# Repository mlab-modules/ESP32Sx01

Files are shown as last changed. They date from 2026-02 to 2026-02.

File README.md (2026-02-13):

# ESP32Sx01 - ESP32-S3 MLAB module

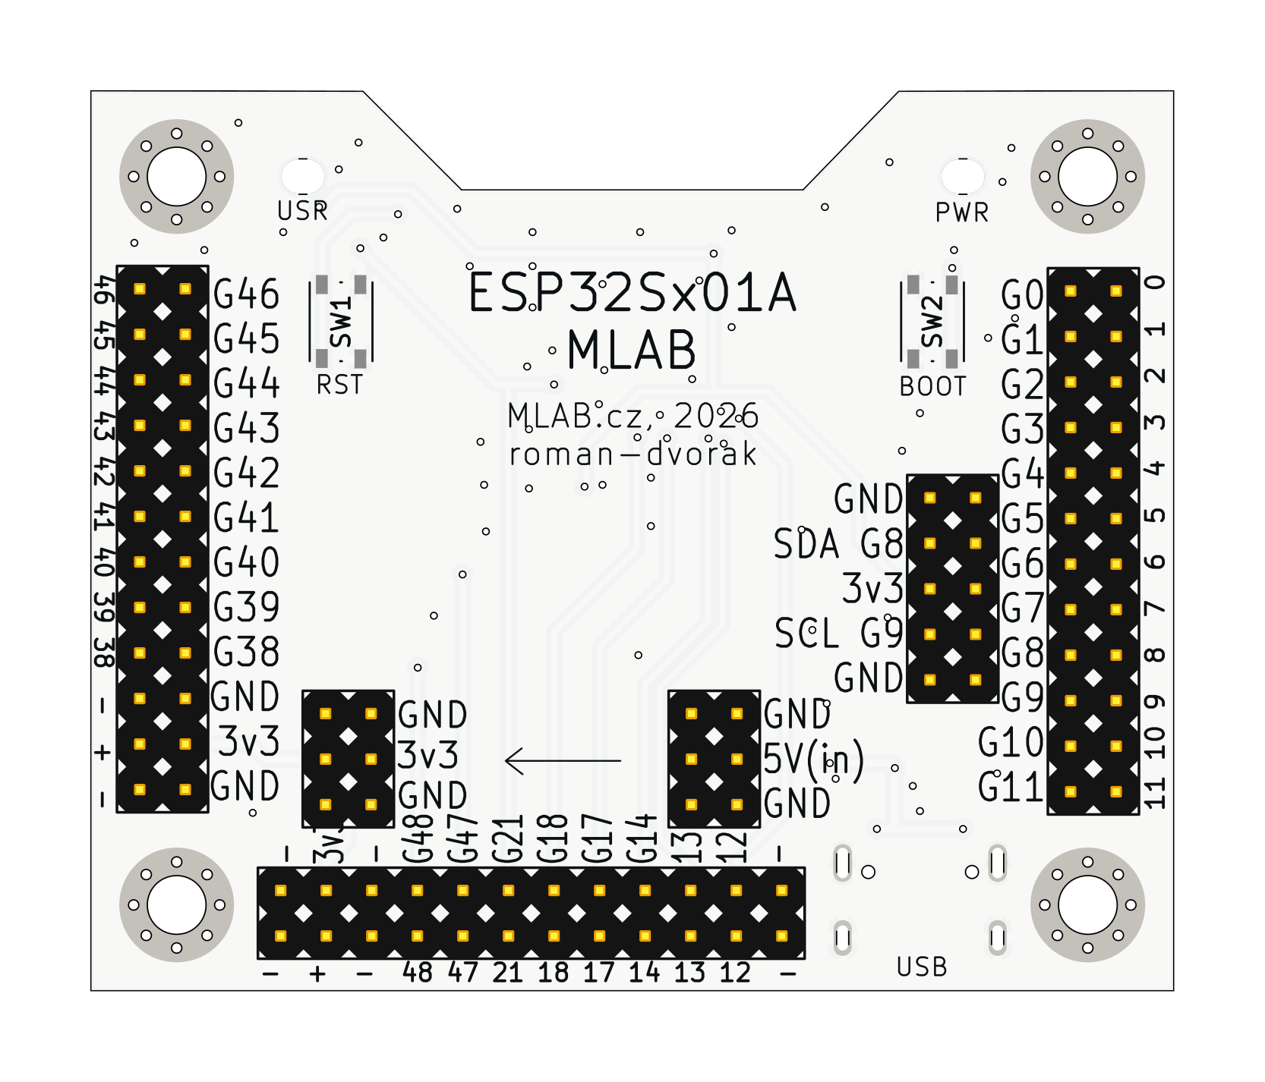
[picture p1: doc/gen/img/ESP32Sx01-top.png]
Module Photo


## Description

ESP32Sx01 is a compact MLAB development module based on the ESP32-S3-MINI-1 microcontroller module from Espressif. The module provides a complete development platform for IoT applications with WiFi and Bluetooth connectivity.

## Key Features

* **Microcontroller**: ESP32-S3-MINI-1
  * Dual-core Xtensa® 32-bit LX7 microprocessor
  * WiFi 802.11 b/g/n (2.4 GHz)
  * Bluetooth® 5 (LE)
  * Up to 8 MB Flash
  * Optional 2 MB PSRAM
* **USB Connectivity**: 2x USB Type-C connectors
  * USB programming and debugging
  * ESD protection (USBLC6-2SC6)
* **Power Supply**:
  * Onboard 3.3V regulator (NCP1117-3.3)
  * Input voltage: +5V via USB or external connector
  * Output: +3.3V for ESP32-S3 and peripherals
* **User Interface**:
  * Reset button
  * Power LED (Green)
  * User LED (Red)
* **Expansion**: 
  * MLAB standard connectors
  * Multiple pin headers for GPIO access
  * Crystal oscillator for precise timing
* **Protection**:
  * USB ESD protection

## Applications

* IoT sensor nodes
* WiFi/Bluetooth gateways
* Home automation controllers
* Wireless data logging
* Educational projects
* Rapid prototyping

## Pinout
The module provides access to ESP32-S3 GPIO pins through standard MLAB connectors and pin headers. Refer to the schematic for detailed pinout information.

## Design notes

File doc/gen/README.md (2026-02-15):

# PCB

Board size: 60.45x50.29 mm (2.38x1.98 inches)

- This is the size of the rectangle that contains the board
- Thickness: 1.6 mm (63 mils)
- Material: FR4
- Finish: None
- Layers: 2
- Copper thickness: 35 µm

Solder mask: TOP / BOTTOM

- Color: Green

Silk screen: TOP / BOTTOM

- Color: White

Stackup:

| Name | Type | Color | Thickness [µm]| Material | Er | Loss tan |
|---|---|---|---|---|---|---|
| F.SilkS | Top Silk Screen | | | | | |
| F.Paste | Top Solder Paste | | | | | |
| F.Mask | Top Solder Mask | | 10 | | | |
| F.Cu | copper | | 35 | | | |
| dielectric 1 | core | | 1510 | FR4 | 4.5 | 0.020 |
| B.Cu | copper | | 35 | | | |
| B.Mask | Bottom Solder Mask | | 10 | | | |
| B.Paste | Bottom Solder Paste  | | | | | |
| B.SilkS | Bottom Silk Screen | | | | | |

# Important sizes

Clearance: 0.2 mm (8 mils)

Track width: 0.2 mm (8 mils)

- By design rules: 0.0 mm (0 mils)

Drill: 0.4 mm (16 mils)

- Vias: 0.4 mm (16 mils) [Design: 0.4 mm (16 mils)]
- Pads: 0.6 mm (24 mils)
- The above values are real drill sizes, they add 0.1 mm (4 mils) to plated holes (PTH)

Via: 0.6/0.3 mm (24/12 mils)

- By design rules: 0.25/0.3 mm (10/12 mils)
- Micro via: yes [0.2/0.1 mm (8/4 mils)]
- Buried/blind via: yes
- Total: 70 (thru: 70 buried/blind: 0 micro: 0)

Outer Annular Ring: 0.1 mm (4 mils)

- By design rules: 0.1 mm (4 mils)

Eurocircuits class: 8C
- Using min drill 0.35 mm for an OAR of 0.1 mm

# General stats

Components count: (SMD/THT)

- Top: 2/6 (SMD + THT)
- Bottom: 24/1 (SMD + THT)

Defined tracks:

- 0.3 mm (12 mils)
- 0.4 mm (16 mils)

Used tracks:

- 0.2 mm (8 mils) (7) defined: no
- 0.25 mm (10 mils) (19) defined: no
- 0.3 mm (12 mils) (119) defined: yes
- 0.4 mm (16 mils) (143) defined: yes

Defined vias:

Used vias:

- 0.6/0.3 mm (24/12 mils) (Count: 70, Aspect: 2.7 A) defined: no

Holes (excluding vias):

- 0.5 mm (20 mils) (32)
- 0.65 mm (26 mils) (2)
- 0.89 mm (35 mils) (94)
- 3.2 mm (126 mils) (4)

Oval holes:

- 0.6x1.4 mm (24x55 mils) (2)
- 0.6x1.7 mm (24x67 mils) (2)
- 1.9x2.4 mm (75x94 mils) (2)

Drill tools (including vias and computing adjusts and rounding):

- 0.4 mm (16 mils) (70)
- 0.6 mm (24 mils) (32)
- 0.65 mm (26 mils) (2)
- 0.7 mm (28 mils) (4)
- 1.0 mm (39 mils) (94)
- 1.9 mm (75 mils) (2)
- 3.3 mm (130 mils) (4)

Solder paste stats:

Using a paste with 87.75 % alloy, that has an specific gravity for the alloy of 7.4 g/cm³
and 1.0 g/cm³ for the flux. This paste has an specific gravity of  4.15 g/cm³.

The stencil thickness is  0.12 mm.

| Side | Pads with paste | Area [mm²] | Paste [g] |
|---|---|---|---|
| Top | 8 | 5.46 | 0.03 |
| Bottom | 138 | 119.78 | 0.60 |
| Total  | 146 | 125.24 | 0.62 |

Note: this is just an approximation to the theoretical value. Margins of the solder mask and waste aren't computed.

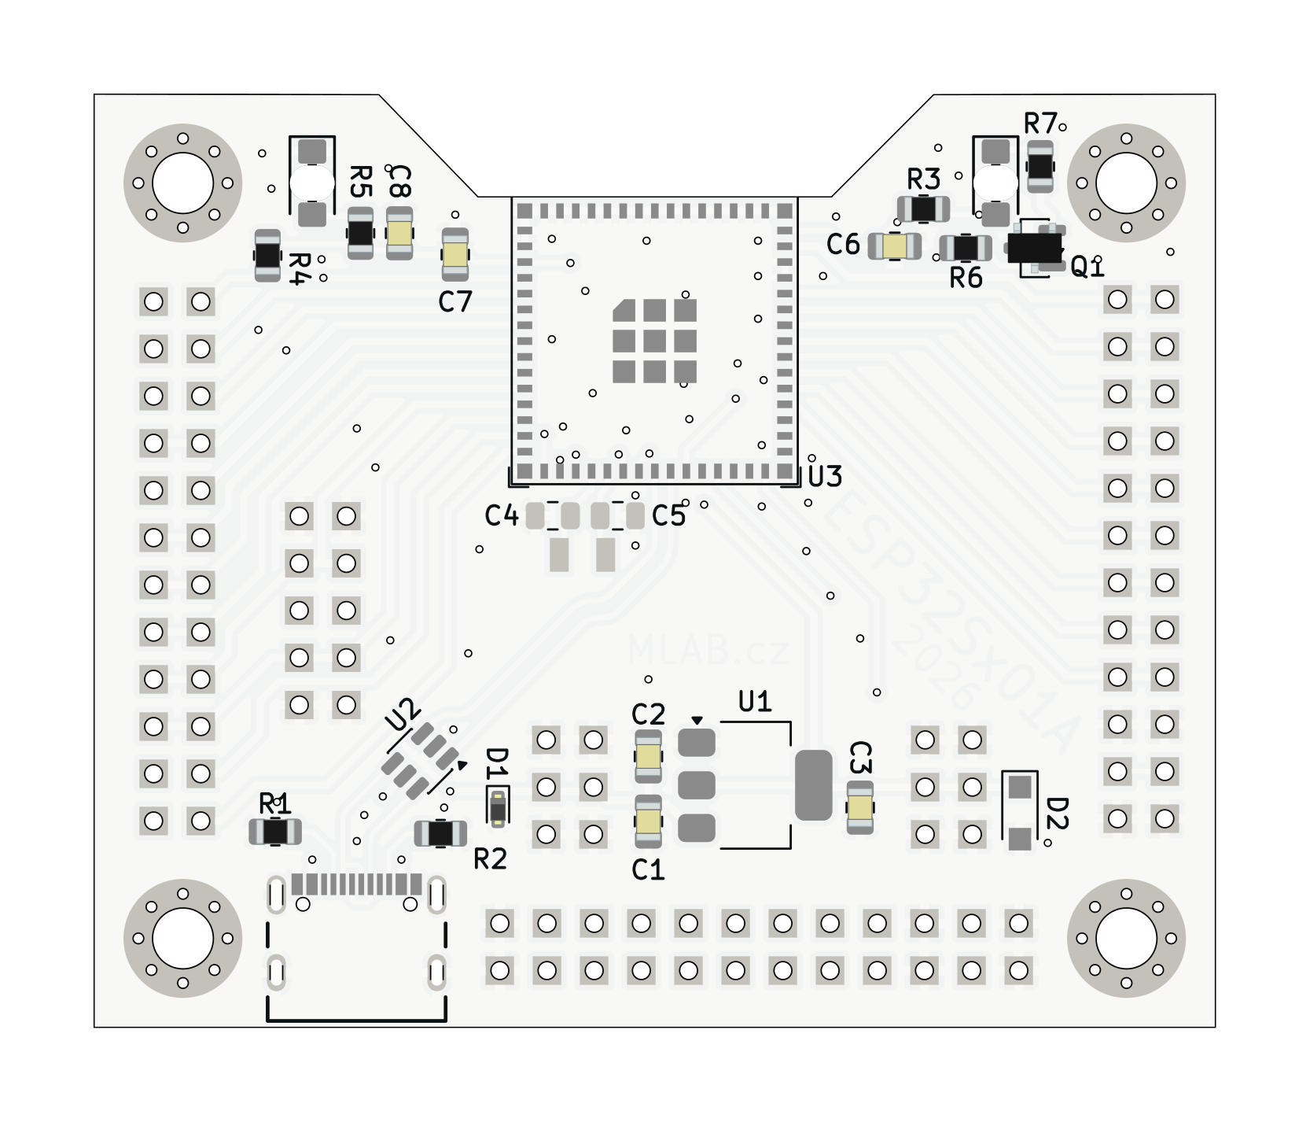
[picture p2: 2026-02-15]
doc/gen/img/ESP32Sx01-bottom.png

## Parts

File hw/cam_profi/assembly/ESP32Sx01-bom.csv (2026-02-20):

Component | Description | Part | References | Value | Footprint | Quantity Per PCB | Datasheet | obchod | ust_id
1 | Unpolarized capacitor, small symbol | C_Small | C1C6C7 | 100n | C_0805_2012Metric | 3 | ~ | TME | 5c70984712875079b91f8b4c
2 | Unpolarized capacitor, small symbol | C_Small | C2C3C8 | 10u | C_0805_2012Metric | 3 | ~ | TME | 5c70984712875079b91f8b53
3 | Zener diode, small symbol | D_Zener_Small | D2 | BZT52H-C3V6,115 | Nexperia_CFP3_SOD-123W | 1 | ~ |  | 650b35ab462c6d9e720543d0
4 | Zener diode, small symbol | D_Zener_Small | D1 | BZX585-B5V6.115 | D_SOD-523 | 1 | ~ |  | 60879d38128750769ee58e48
5 | Light emitting diode, small symbol | LED_Small | D4 | Green | LED_1206_KPTR | 1 | ~ | OK
6 | Light emitting diode, small symbol | LED_Small | D3 | Red | LED_1206_KPTR | 1 | ~ | OK
7 | 2x03 2.54 mm pitch header, 2 pins next to each other are connected | HEADER_2x03_PARALLEL | J1J6 | HEADER_1x03 | Straight_2x03 | 2
8 | 2x12 2.54 mm pitch header, 2 pins next to each other are connected | HEADER_2x12_PARALLEL | J3J4J5 | HEADER_1x12 | Straight_2x12 | 3
9 | 2x05 2.54 mm pitch header, 2 pins next to each other are connected | HEADER_2x05_PARALLEL | J7 | HEADER_2x05 | Straight_2x05 | 1
10 | USB 2.0-only Type-C Receptacle connector | USBC_USB4105-GF-A | J2 | USBC_USB4105-GF-A | USBC GCT_USB4105-GF-A | 1 | https://www.usb.org/sites/default/files/documents/usb_type-c.zip | OK | 5fa0f94612875025b397795e
11 | NPN transistor, base/collector/emitter | Q_NPN_BCE | Q1 | BC817-25 | SOT-23 | 1 | ~ | TME | 5c70984712875079b91f8aea
12 | Resistor, small symbol | R_Small | R5R6 | 200R | R_0805_2012Metric | 2 | ~ | TME | 5c70984512875079b91f897d
13 | Resistor, small symbol | R_Small | R7 | 390R | R_0805_2012Metric | 1 | ~ |  | 5fa12b6012875025b3977a16
14 | Resistor, small symbol | R_Small | R3R4 | 1k | R_0805_2012Metric | 2 | ~ | TME | 5c70984512875079b91f898c
15 | Resistor, small symbol | R_Small | R1R2 | 5k1 | R_0805_2012Metric | 2 | ~ | TME | 5fa0fc3e12875025b3977997
16 | Push button switch, generic, two pins | SW_Push | SW1SW2 | 434133025816 | SW_Push_1P1T_NO_Vertical_Wuerth_434133025816 | 2 | ~ | TME | 6998c49ed42e6e3c4d330f22
17 | Smallsized module supporting 2.4 GHz WiFi (802.11 b/g/n) and Bluetooth ® 5 (LE) Built around ESP32S3 series of SoCs, Xtensa ® dualcore 32bit LX7 microprocessor Flash up to 8 MB, optional 2 MB PSRAM in chip package 39 GPIOs, rich set of peripherals Onboard PCB antenna or external antenna connector | ESP32-S3-MINI-1 | U3 | ESP32-S3-MINI-1 | ESP32-S3-MINI-1 | 1 | https://www.espressif.com/sites/default/files/documentation/esp32-s3-mini-1_mini-1u_datasheet_en.pdf
18 | 1A Low drop-out regulator, Fixed Output 3.3V, SOT-223 | NCP1117-3.3_SOT223 | U1 | NCP1117-3.3 | SOT-223-3_TabPin2 | 1 | http://www.onsemi.com/pub_link/Collateral/NCP1117-D.PDF | TME | 5c70984712875079b91f8af9
19 | Very low capacitance ESD protection diode, 2 data-line, SOT-23-6 | USBLC6-2SC6 | U2 | USBLC6-2SC6 | SOT-23-6 | 1 | https://www.st.com/resource/en/datasheet/usblc6-2.pdf | TME | 5e82e0691287502a334a778c

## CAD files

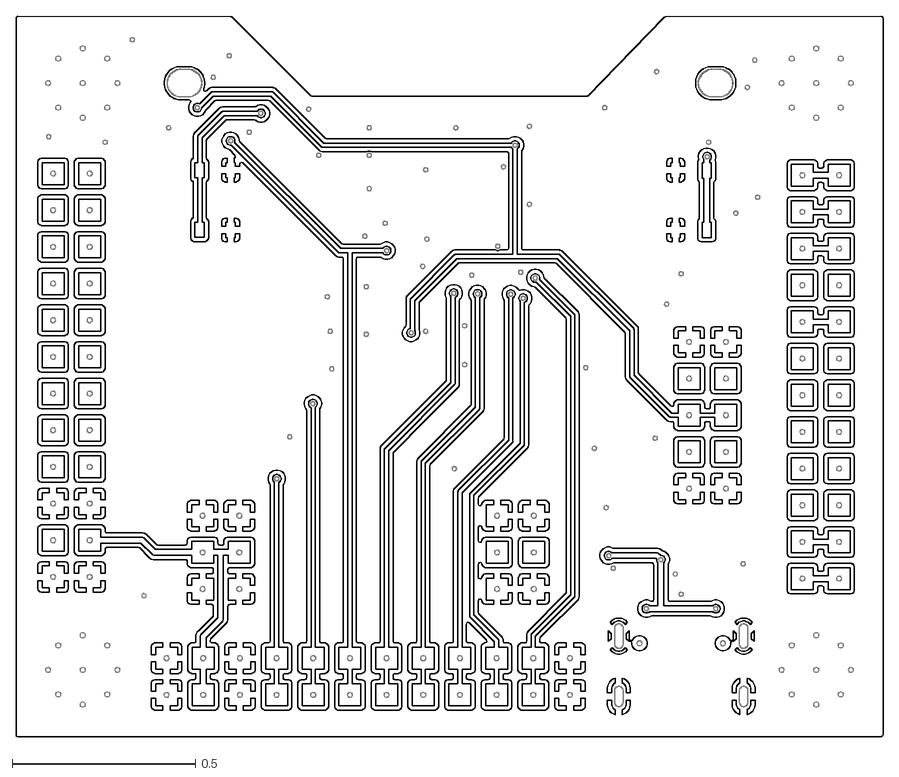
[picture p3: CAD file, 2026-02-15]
doc/gen/dxf/ESP32Sx01-F_Cu.dxf
2.36 x 1.96

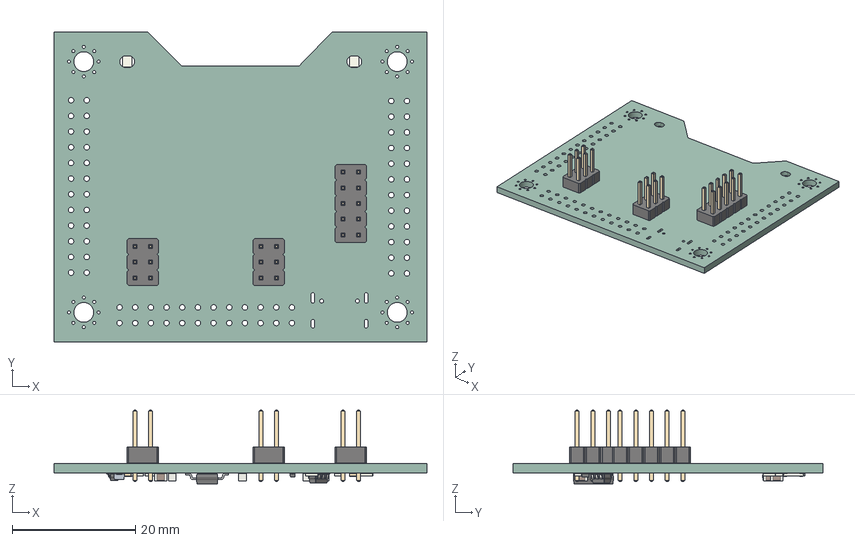
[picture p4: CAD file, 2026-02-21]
doc/gen/ESP32Sx01.step
60.5 x 50.3 x 11.9 mm
PinHeader_2x03_P2.54mm_Vertical x 2
PinHeader_2x05_P2.54mm_Vertical
R_0805_2012Metric x 7
C_0805_2012Metric x 6
LED_1206_3216Metric x 2
ESP32Sx01 1.10.1
SOT-223
D_SOD-523
SOT-23
SOT-23-6
kibot_rp9vfimv_PCB

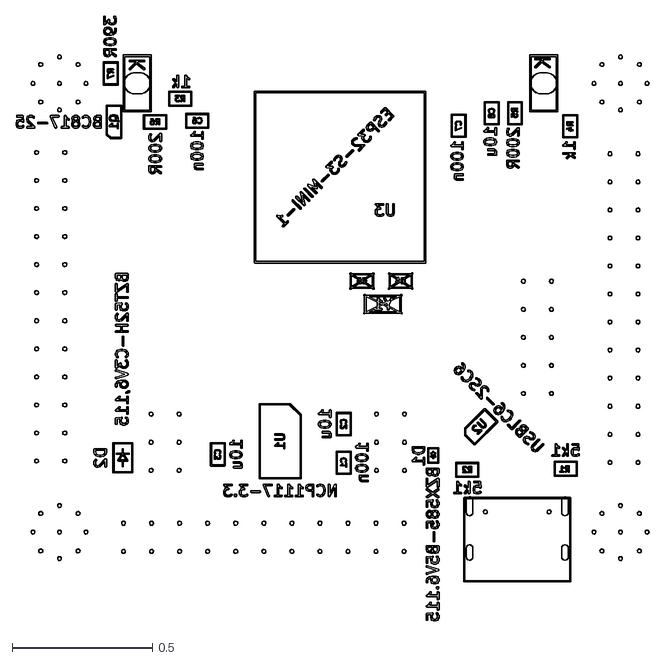
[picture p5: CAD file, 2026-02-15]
doc/gen/dxf/ESP32Sx01-B_Fab.dxf
2.26 x 2.16

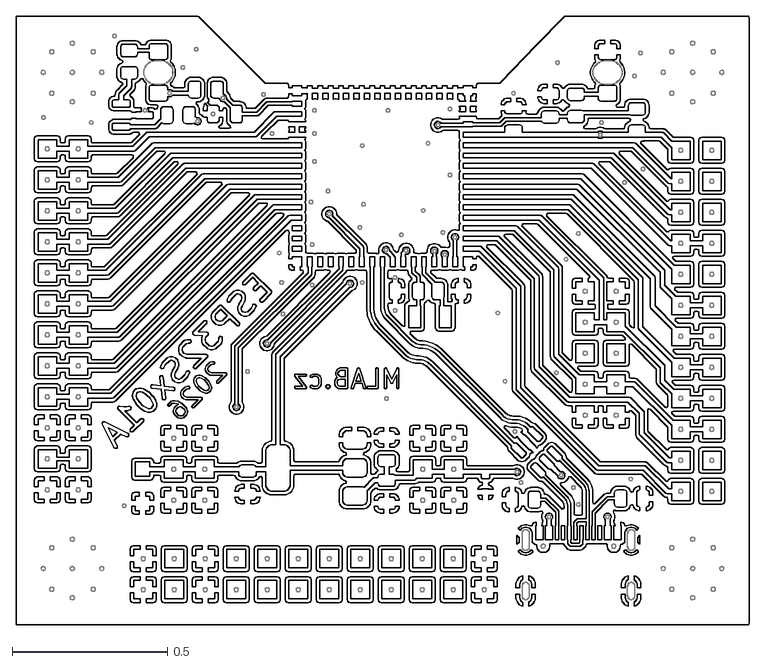
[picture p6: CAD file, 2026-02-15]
doc/gen/dxf/ESP32Sx01-B_Cu.dxf
2.36 x 1.96

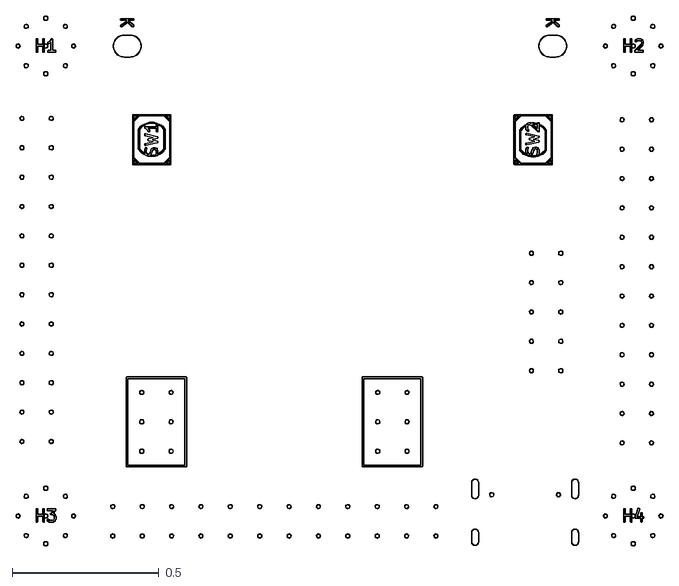
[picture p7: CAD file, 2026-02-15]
doc/gen/dxf/ESP32Sx01-F_Fab.dxf
2.20 x 1.80

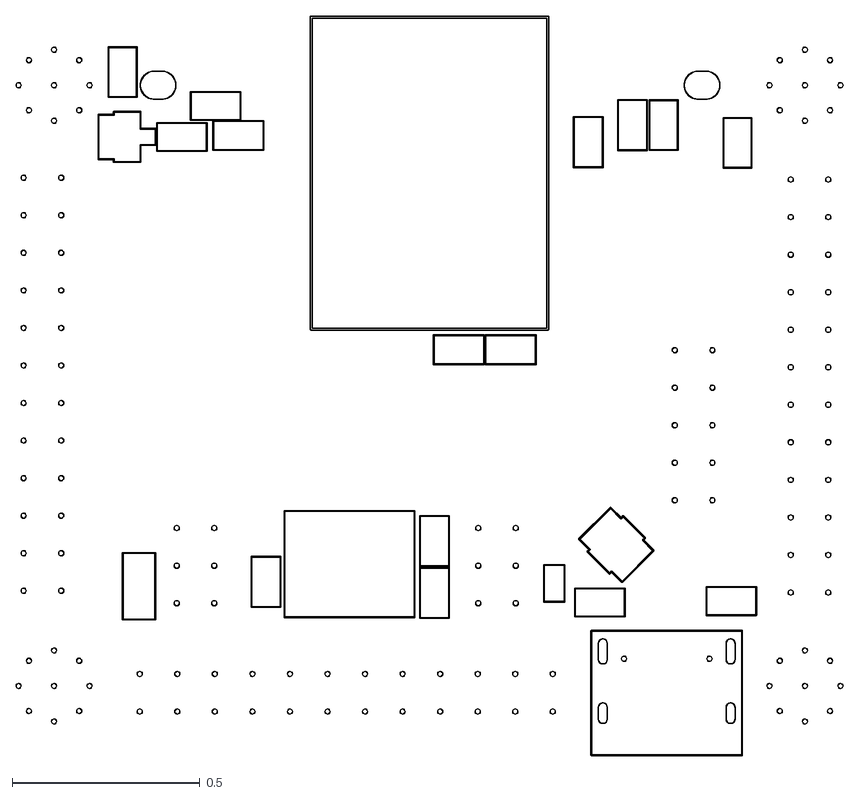
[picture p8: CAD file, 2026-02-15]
doc/gen/dxf/ESP32Sx01-B_Courtyard.dxf
2.20 x 1.97

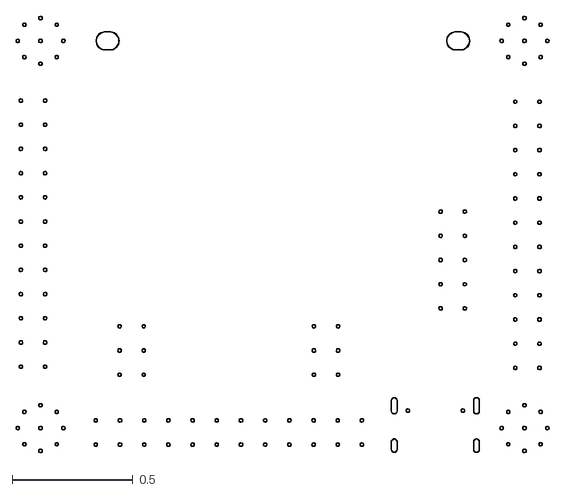
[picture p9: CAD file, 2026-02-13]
doc/gen/dxf/ESP32Sx01-User_1.dxf
2.20 x 1.80

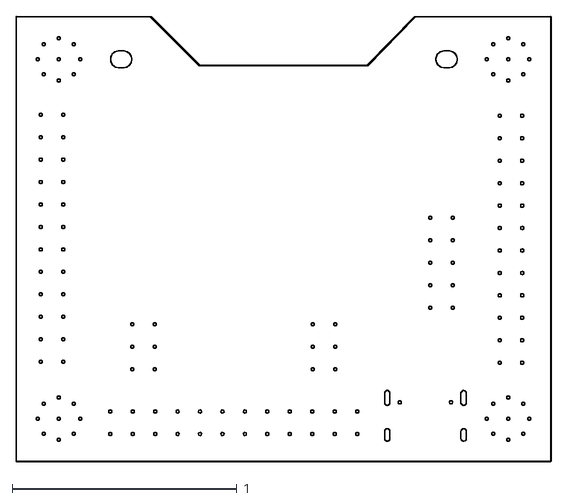
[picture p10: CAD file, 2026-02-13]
doc/gen/dxf/ESP32Sx01-Edge_Cuts.dxf
2.38 x 1.98

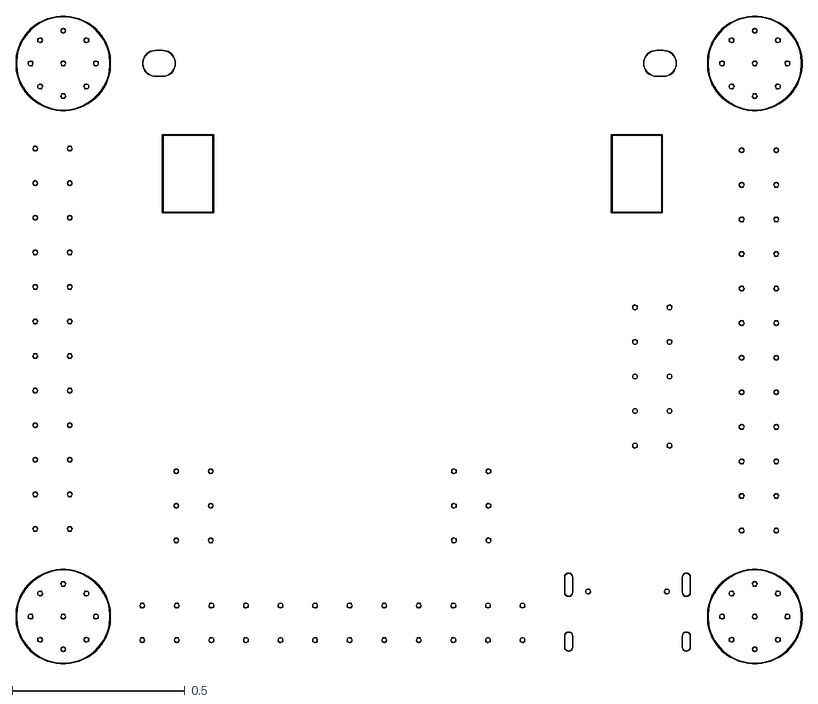
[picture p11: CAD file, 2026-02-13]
doc/gen/dxf/ESP32Sx01-F_Courtyard.dxf
2.27 x 1.87

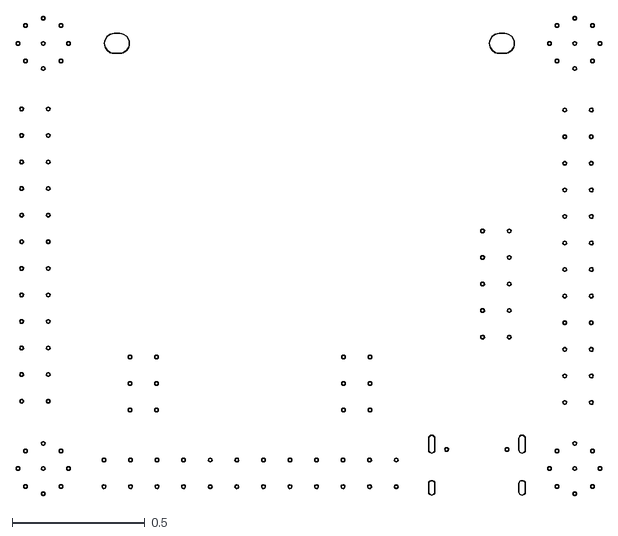
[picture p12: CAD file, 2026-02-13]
doc/gen/dxf/ESP32Sx01-F_Adhesive.dxf
2.20 x 1.80

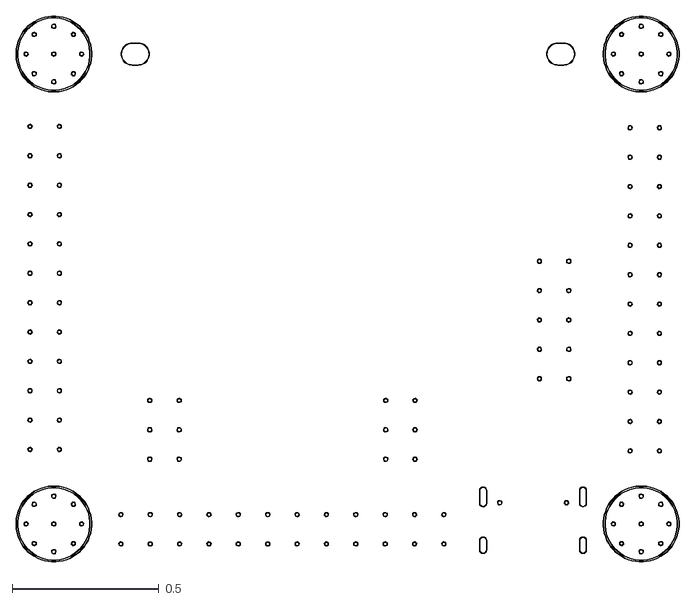
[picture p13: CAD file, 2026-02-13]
doc/gen/dxf/ESP32Sx01-User_Comments.dxf
2.26 x 1.86

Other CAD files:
doc/gen/dxf/ESP32Sx01-B_Mask.dxf
doc/gen/dxf/ESP32Sx01-B_Paste.dxf
doc/gen/dxf/ESP32Sx01-B_Silkscreen.dxf
doc/gen/dxf/ESP32Sx01-F_Mask.dxf
doc/gen/dxf/ESP32Sx01-F_Paste.dxf
doc/gen/dxf/ESP32Sx01-F_Silkscreen.dxf

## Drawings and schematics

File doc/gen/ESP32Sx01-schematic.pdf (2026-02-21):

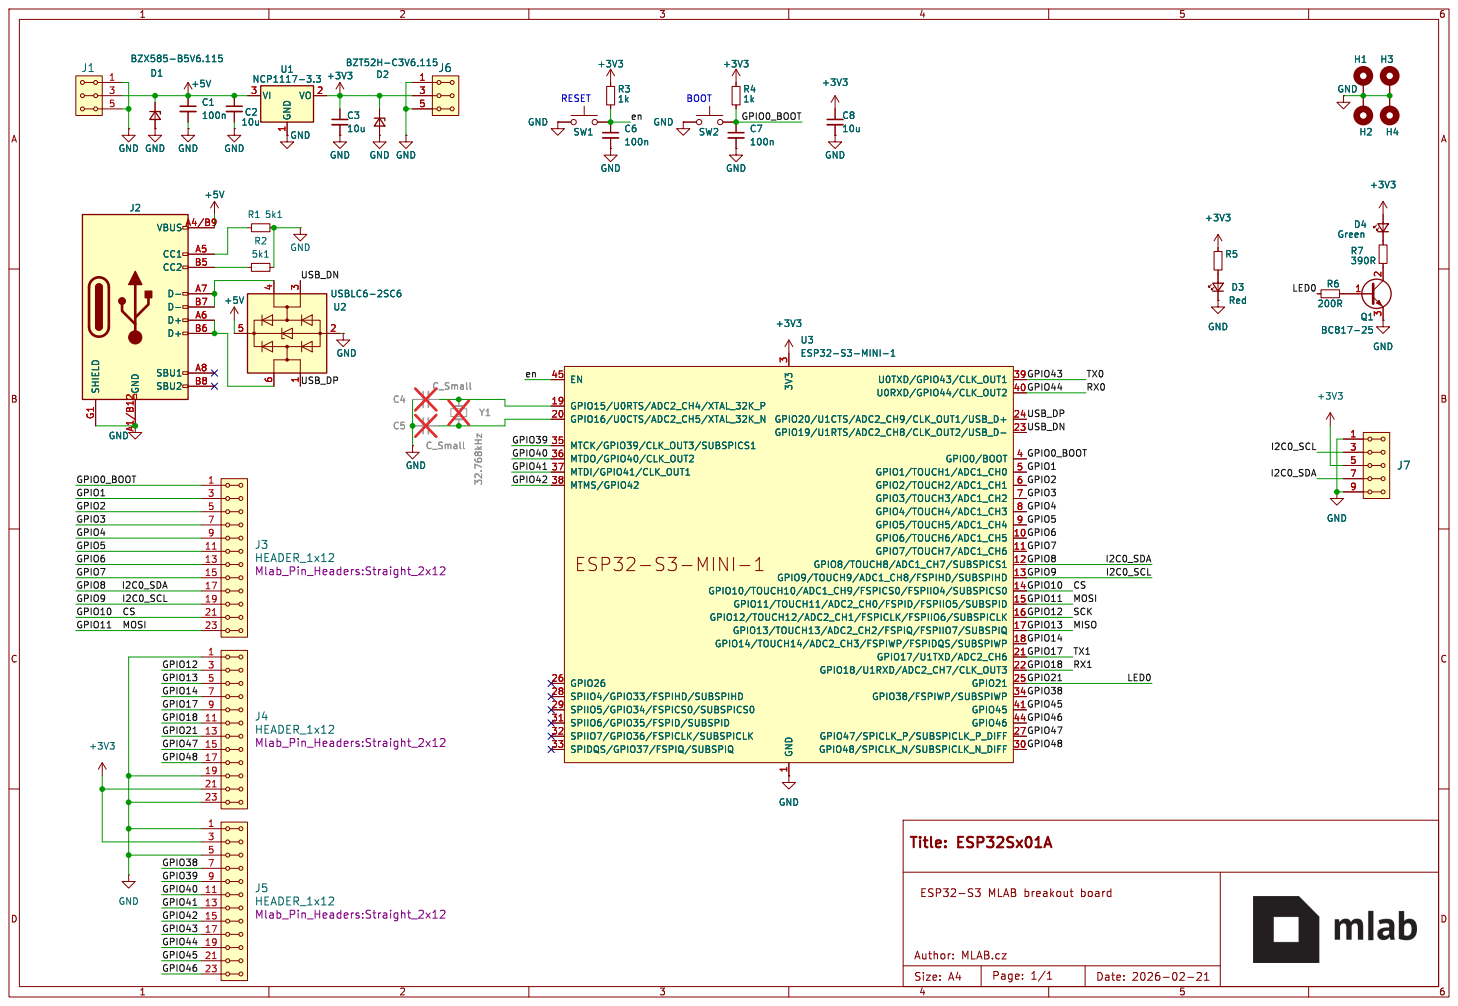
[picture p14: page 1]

1 U0TXD/GPIO43/CLK_OUT1 39 U0RXD/GPIO44/CLK_OUT2 40 GPIO20/U1CTS/ADC2_CH9/CLK_OUT1/USB_D+ 24 GPIO19/U1RTS/ADC2_CH8/CLK_OUT2/USB_D- 23 GPIO0/BOOT 4 GPIO1/TOUCH1/ADC1_CH0 5 GPIO2/TOUCH2/ADC1_CH1 6 GPIO3/TOUCH3/ADC1_CH2 7 GPIO4/TOUCH4/ADC1_CH3 8 GPIO5/TOUCH5/ADC1_CH4 9 GPIO6/TOUCH6/ADC1_CH5 10 GPIO7/TOUCH7/ADC1_CH6 11 GPIO8/TOUCH8/ADC1_CH7/SUBSPICS1 12 GPIO9/TOUCH9/ADC1_CH8/FSPIHD/SUBSPIHD 13 GPIO10/TOUCH10/ADC1_CH9/FSPICS0/FSPIIO4/SUBSPICS0 14 GPIO11/TOUCH11/ADC2_CH0/FSPID/FSPIIO5/SUBSPID 15 GPIO12/TOUCH12/ADC2_CH1/FSPICLK/FSPIIO6/SUBSPICLK 16 GPIO13/TOUCH13/ADC2_CH2/FSPIQ/FSPIIO7/SUBSPIQ 17 GPIO14/TOUCH14/ADC2_CH3/FSPIWP/FSPIDQS/SUBSPIWP 18 GPIO17/U1TXD/ADC2_CH6 21 GPIO18/U1RXD/ADC2_CH7/CLK_OUT3 22 GPIO21 25 GPIO38/FSPIWP/SUBSPIWP 34 GPIO45 41 GPIO46 44 GPIO47/SPICLK_P/SUBSPICLK_P_DIFF 27 GPIO48/SPICLK_N/SUBSPICLK_N_DIFF 30 U3ESP32-S3-MINI-1 SW2 +3V3 GND

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

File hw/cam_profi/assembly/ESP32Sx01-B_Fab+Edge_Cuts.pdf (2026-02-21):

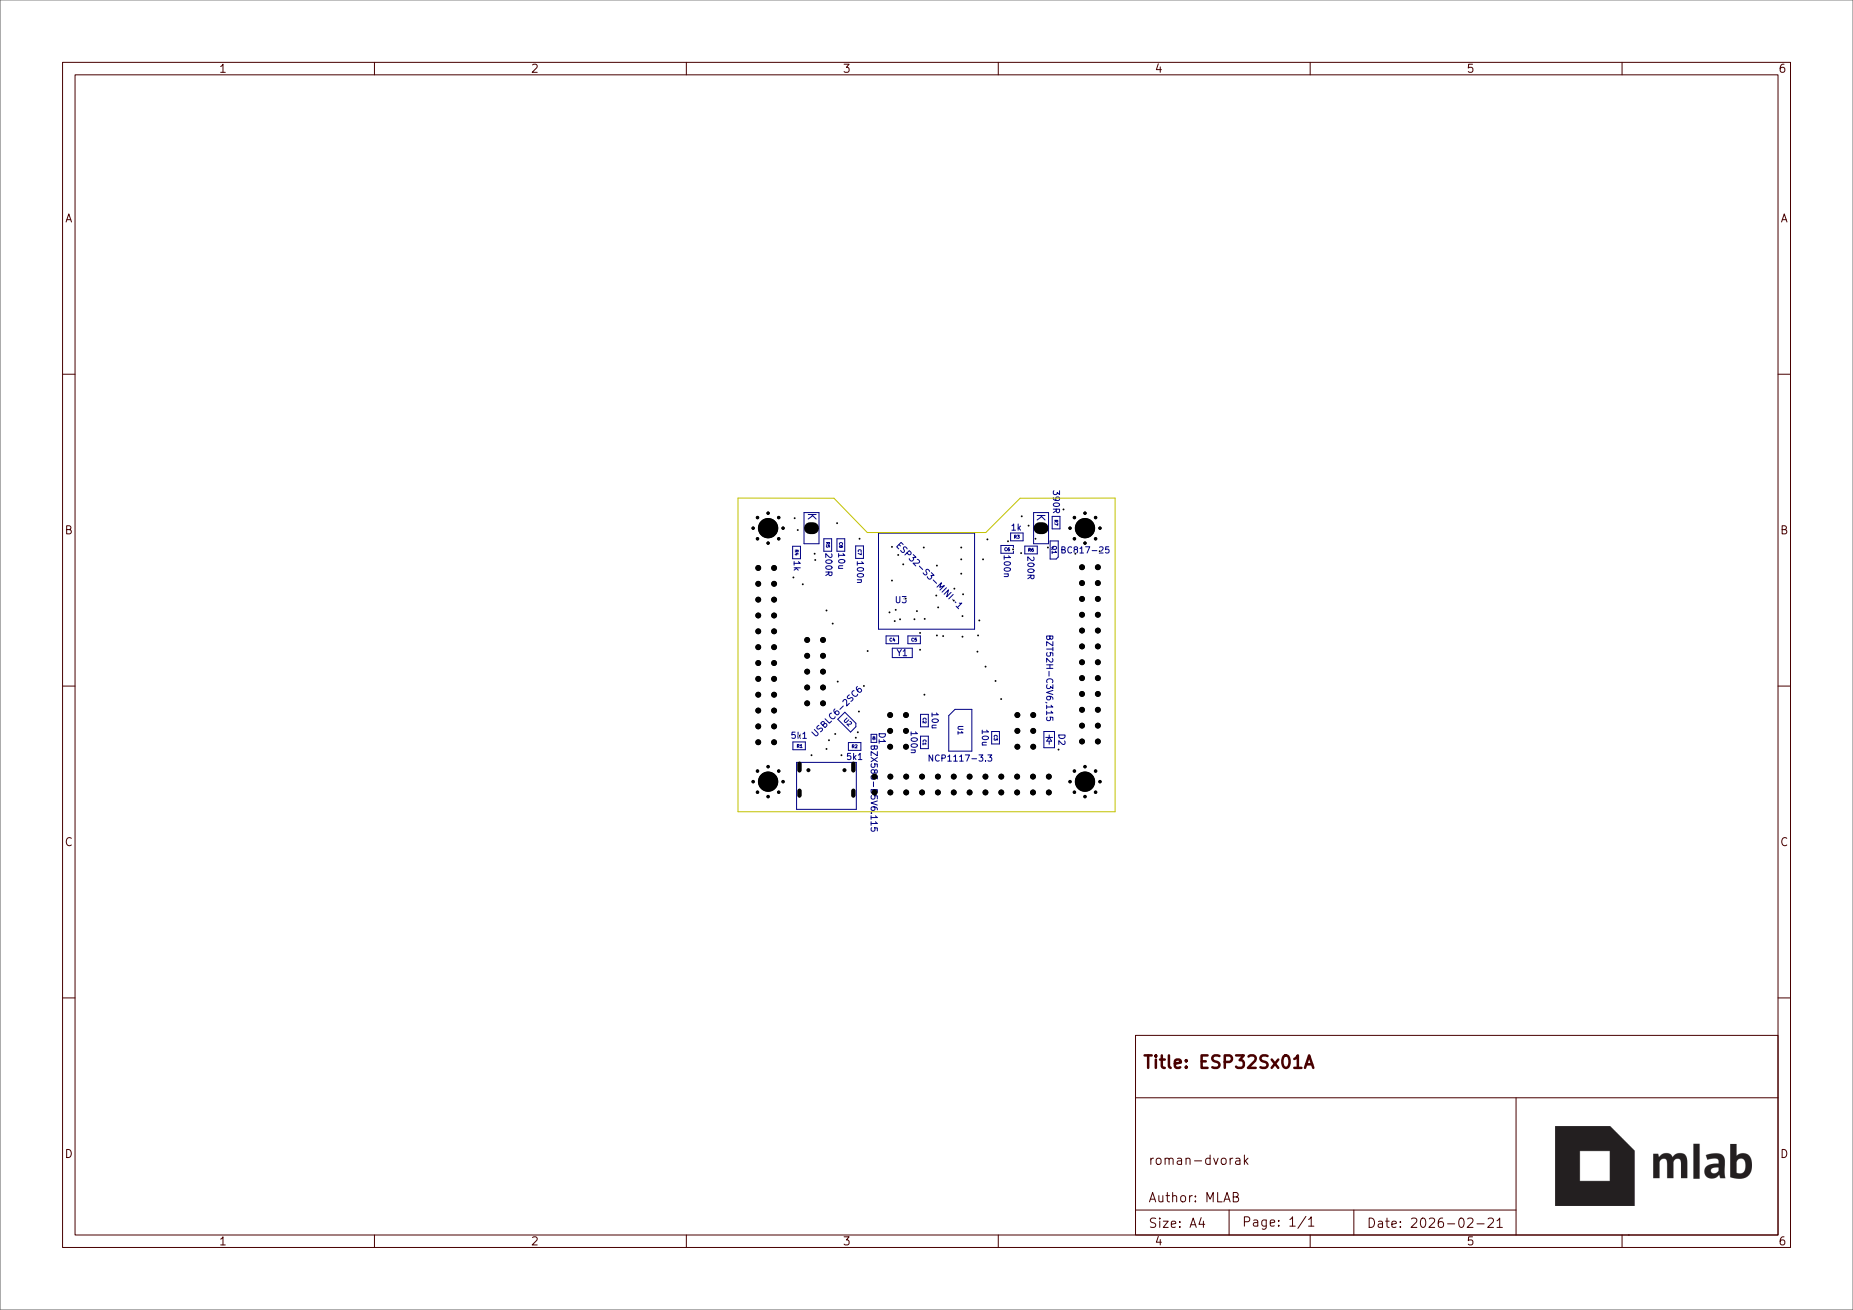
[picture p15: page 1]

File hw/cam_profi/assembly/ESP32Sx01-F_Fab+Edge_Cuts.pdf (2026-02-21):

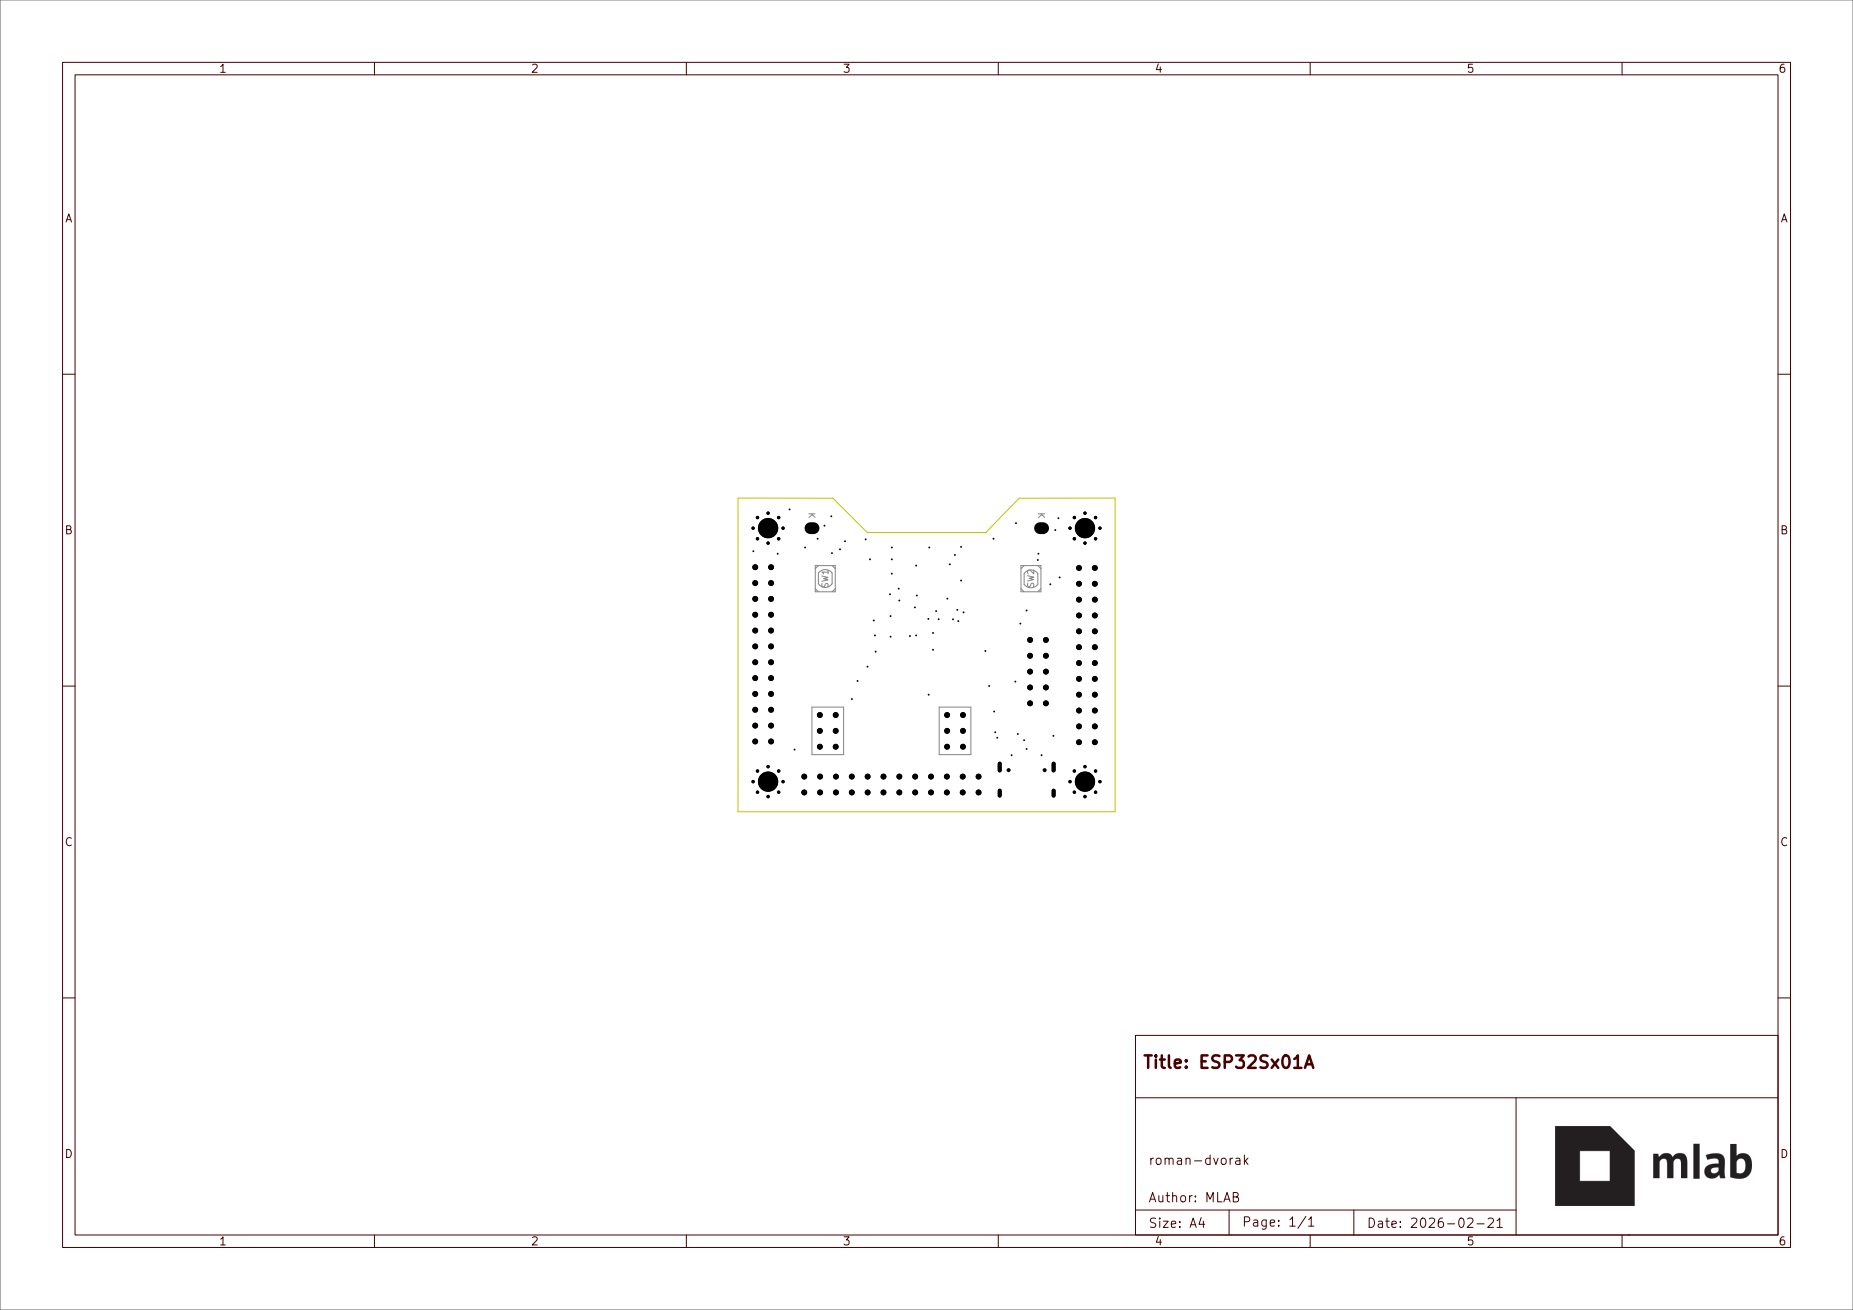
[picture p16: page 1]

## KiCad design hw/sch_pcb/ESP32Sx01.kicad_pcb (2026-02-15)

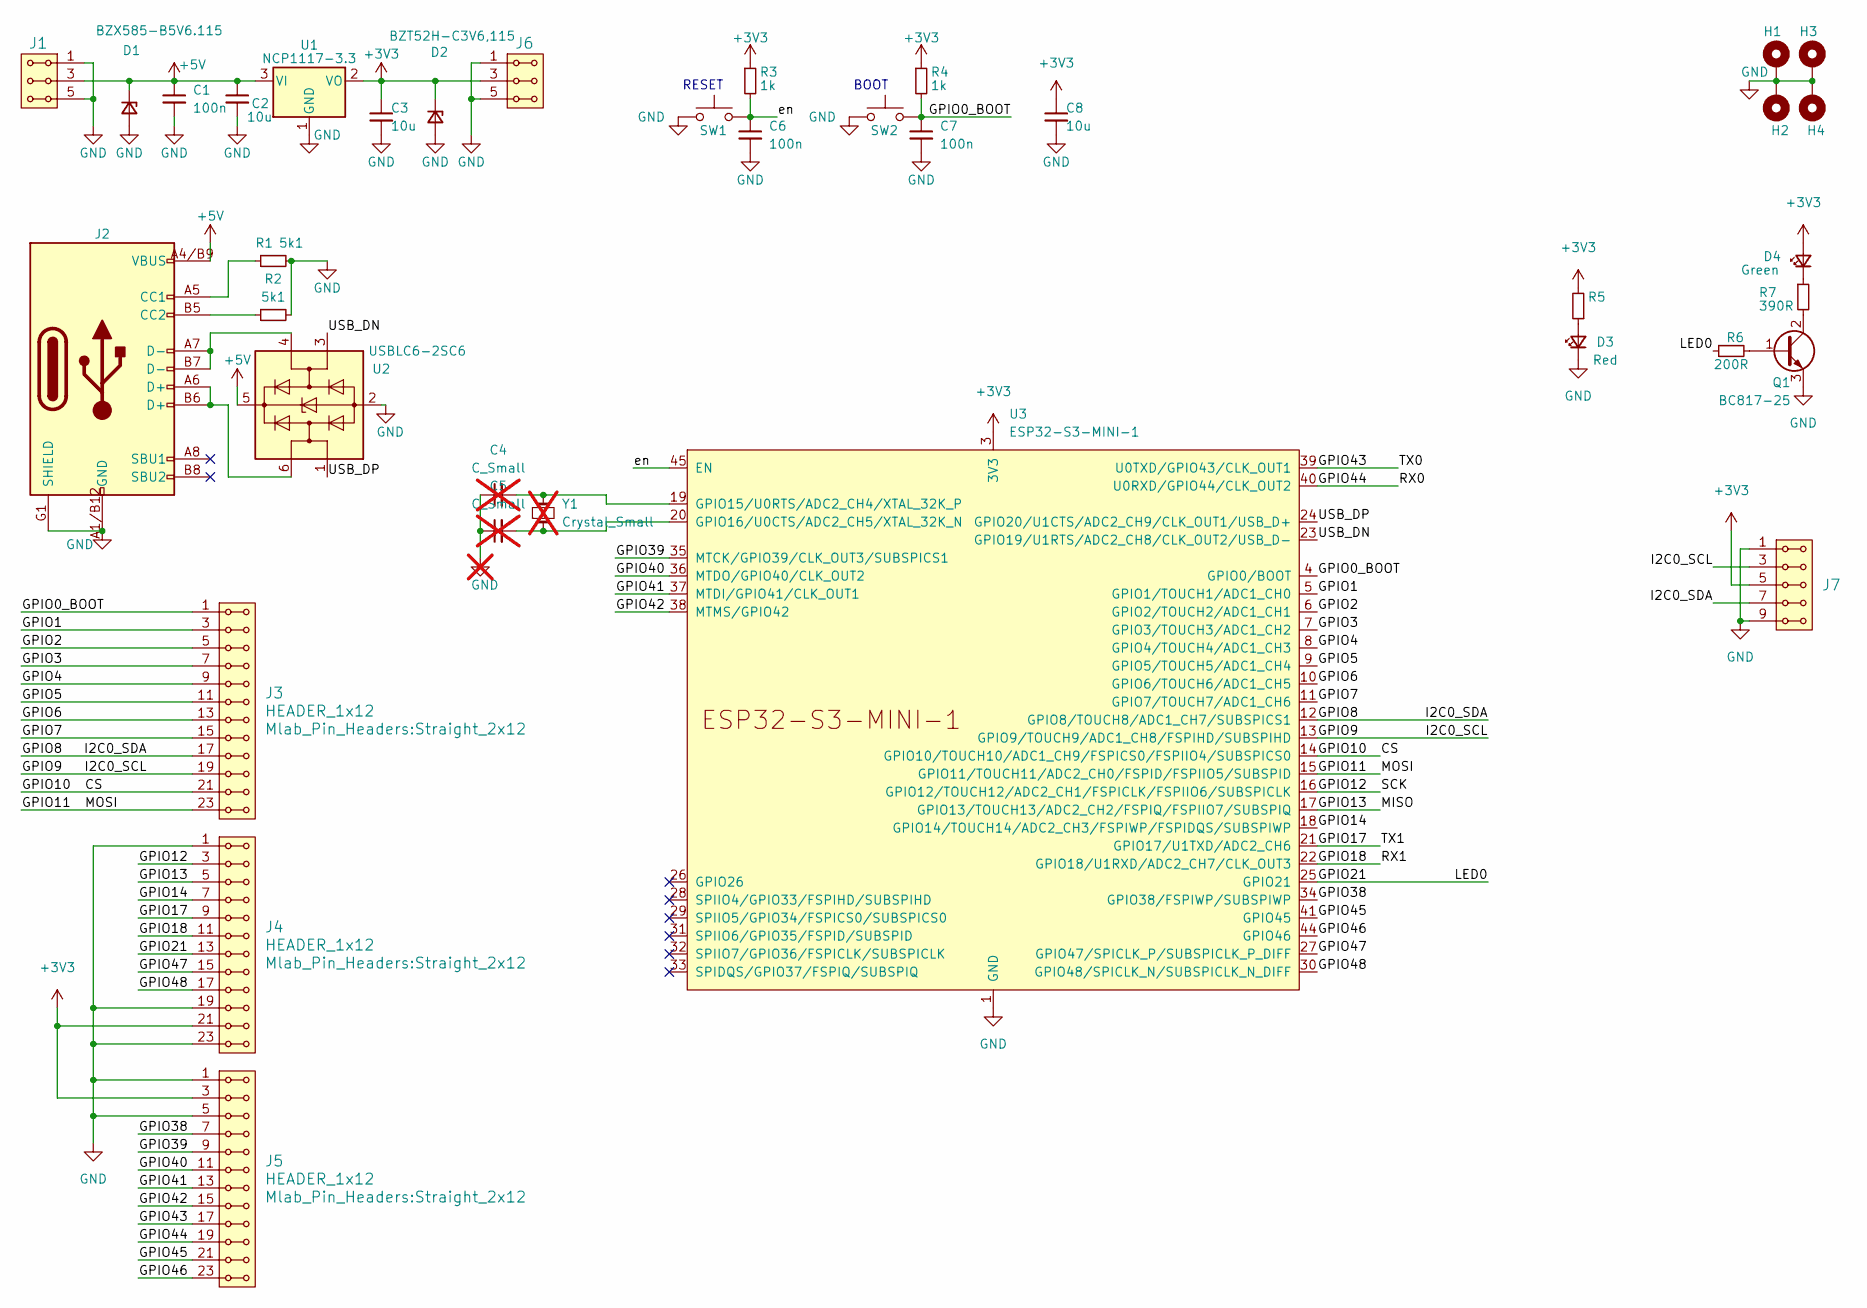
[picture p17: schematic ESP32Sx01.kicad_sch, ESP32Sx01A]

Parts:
C1, C6, C7: 100n; C_0805_2012Metric
C2, C3, C8: 10u; C_0805_2012Metric
C4, C5: C_Small; C_0805_2012Metric; not fitted
D1: BZX585-B5V6.115; D_SOD-523
D2: BZT52H-C3V6,115; Nexperia_CFP3_SOD-123W
D3: Red; LED_1206_KPTR
D4: Green; LED_1206_KPTR
H1, H2, H3, H4: MountingHole_Pad; MountingHole_3.2mm_M3_Pad_Via
J1, J6: HEADER_1x03; Straight_2x03
J2: USBC_USB4105-GF-A; USBC GCT_USB4105-GF-A
J3, J4, J5: HEADER_1x12; Straight_2x12
J7: HEADER_2x05; Straight_2x05
Q1: BC817-25; SOT-23
R1, R2: 5k1; R_0805_2012Metric
R3, R4: 1k; R_0805_2012Metric
R5, R6: 200R; R_0805_2012Metric
R7: 390R; R_0805_2012Metric
SW1, SW2: 434133025816; SW_Push_1P1T_NO_Vertical_Wuerth_434133025816
U1: NCP1117-3.3; SOT-223-3_TabPin2
U2: USBLC6-2SC6; SOT-23-6
U3: ESP32-S3-MINI-1
Y1: Crystal_Small; ABS07; not fitted

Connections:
+3V3: C3.1, C8.1, D2.1 (K), D4.2 (A), J4.21, J4.22, J5.3, J5.4, J6.3, J6.4, J7.5, J7.6, R3.1, R4.1, R5.2, U1.2 (VO), U3.3 (3V3)
+5V: C1.1, C2.1, D1.1 (K), J1.3, J1.4, J2.A4/B9 (VBUS), J2.B4/A9 (VBUS), U1.3 (VI), U2.5 (VBUS)
/CS: J3.21, J3.22, U3.14 (GPIO10/TOUCH10/ADC1_CH9/FSPICS0/FSPIIO4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)
/GPIO0_BOOT: C7.1, J3.1, J3.2, R4.2, SW2.2, U3.4 (GPIO0/BOOT)
/GPIO1: J3.3, J3.4, U3.5 (GPIO1/TOUCH1/ADC1_CH0)
/GPIO2: J3.5, J3.6, U3.6 (GPIO2/TOUCH2/ADC1_CH1)
/GPIO3: J3.7, J3.8, U3.7 (GPIO3/TOUCH3/ADC1_CH2)
/GPIO4: J3.9, J3.10, U3.8 (GPIO4/TOUCH4/ADC1_CH3)
/GPIO5: J3.11, J3.12, U3.9 (GPIO5/TOUCH5/ADC1_CH4)
/GPIO6: J3.13, J3.14, U3.10 (GPIO6/TOUCH6/ADC1_CH5)
/GPIO7: J3.15, J3.16, U3.11 (GPIO7/TOUCH7/ADC1_CH6)
/GPIO8: J3.17, J3.18, J7.7, J7.8, U3.12 (GPIO8/TOUCH8/ADC1_CH7/SUBSPICS1)
/GPIO9: J3.19, J3.20, J7.3, J7.4, U3.13 (GPIO9/TOUCH9/ADC1_CH8/FSPIHD/SUBSPIHD)
/GPIO11: J3.23, J3.24, U3.15 (GPIO11/TOUCH11/ADC2_CH0/FSPID/FSPIIO5/S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)
/GPIO12: J4.3, J4.4, U3.16 (GPIO12/TOUCH12/ADC2_CH1/FSPICLK/FSPIIO6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)
/GPIO13: J4.5, J4.6, U3.17 (GPIO13/TOUCH13/ADC2_CH2/FSPIQ/FSPIIO7/S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)
/GPIO14: J4.7, J4.8, U3.18 (GPIO14/TOUCH14/ADC2_CH3/FSPIWP/FSPIDQS/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)
/GPIO17: J4.9, J4.10, U3.21 (GPIO17/U1TXD/ADC2_CH6)
/GPIO18: J4.11, J4.12, U3.22 (GPIO18/U1RXD/ADC2_CH7/CLK_OUT3)
/GPIO21: J4.13, J4.14, R6.1, U3.25 (GPIO21)
/GPIO38: J5.7, J5.8, U3.34 (GPIO38/FSPIWP/SUBSPIWP)
/GPIO39: J5.9, J5.10, U3.35 (MTCK/GPIO39/CLK_OUT3/SUBSPICS1)
/GPIO40: J5.11, J5.12, U3.36 (MTDO/GPIO40/CLK_OUT2)
/GPIO41: J5.13, J5.14, U3.37 (MTDI/GPIO41/CLK_OUT1)
/GPIO42: J5.15, J5.16, U3.38 (MTMS/GPIO42)
/GPIO43: J5.17, J5.18, U3.39 (U0TXD/GPIO43/CLK_OUT1)
/GPIO44: J5.19, J5.20, U3.40 (U0RXD/GPIO44/CLK_OUT2)
/GPIO45: J5.21, J5.22, U3.41 (GPIO45)
/GPIO46: J5.23, J5.24, U3.44 (GPIO46)
/GPIO47: J4.15, J4.16, U3.27 (GPIO47/SPICLK_P/SUBSPICLK_P_DIFF)
/GPIO48: J4.17, J4.18, U3.30 (GPIO48/SPICLK_N/SUBSPICLK_N_DIFF)
/USB_DN: U2.3 (I/O2), U3.23 (GPIO19/U1RTS/ADC2_CH8/CLK_OUT2/USB_D-)
/USB_DP: U2.1 (I/O1), U3.24 (GPIO20/U1CTS/ADC2_CH9/CLK_OUT1/USB_D+)
/en: C6.1, R3.2, SW1.2, U3.45 (EN)
GND: C1.2, C2.2, C3.2, C4.1, C5.1, C6.2, C7.2, C8.2, D1.2 (A), D2.2 (A), D3.1 (K), H1.1, H2.1, H3.1, H4.1, J1.1, J1.2, J1.5, J1.6, J2.A1/B12 (GND), J2.B1/A12 (GND), J2.G1 (SHIELD), J2.G2 (SHIELD), J2.G3 (SHIELD), J2.G4 (SHIELD), J4.1, J4.2, J4.19, J4.20, J4.23, J4.24, J5.1, J5.2, J5.5, J5.6, J6.1, J6.2, J6.5, J6.6, J7.1, J7.2, J7.9, J7.10, Q1.3 (E), R1.2, R2.2, SW1.1, SW2.1, U1.1 (GND), U2.2 (GND), U3.1 (GND), U3.2 (GND), U3.42 (GND), U3.43 (GND), U3.46 (GND), U3.47 (GND), U3.48 (GND), U3.49 (GND), U3.50 (GND), U3.51 (GND), U3.52 (GND), U3.53 (GND), U3.54 (GND), U3.55 (GND), U3.56 (GND), U3.57 (GND), U3.58 (GND), U3.59 (GND), U3.60 (GND), U3.61 (GND), U3.62 (GND), U3.63 (GND), U3.64 (GND), U3.65 (GND)
unnamed: D3.2 (A), R5.1
unnamed: D4.1 (K), R7.1
unnamed: J2.A5 (CC1), R1.1
unnamed: J2.B5 (CC2), R2.1
unnamed: J2.A6 (D+), J2.B6 (D+), U2.6 (I/O1)
unnamed: J2.A7 (D-), J2.B7 (D-), U2.4 (I/O2)
unnamed: Q1.1 (B), R6.2
unnamed: Q1.2 (C), R7.2
unnamed: C4.2, U3.19 (GPIO15/U0RTS/ADC2_CH4/XTAL_32K_P), Y1.1
unnamed: C5.2, U3.20 (GPIO16/U0CTS/ADC2_CH5/XTAL_32K_N), Y1.2

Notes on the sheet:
RESET
BOOT

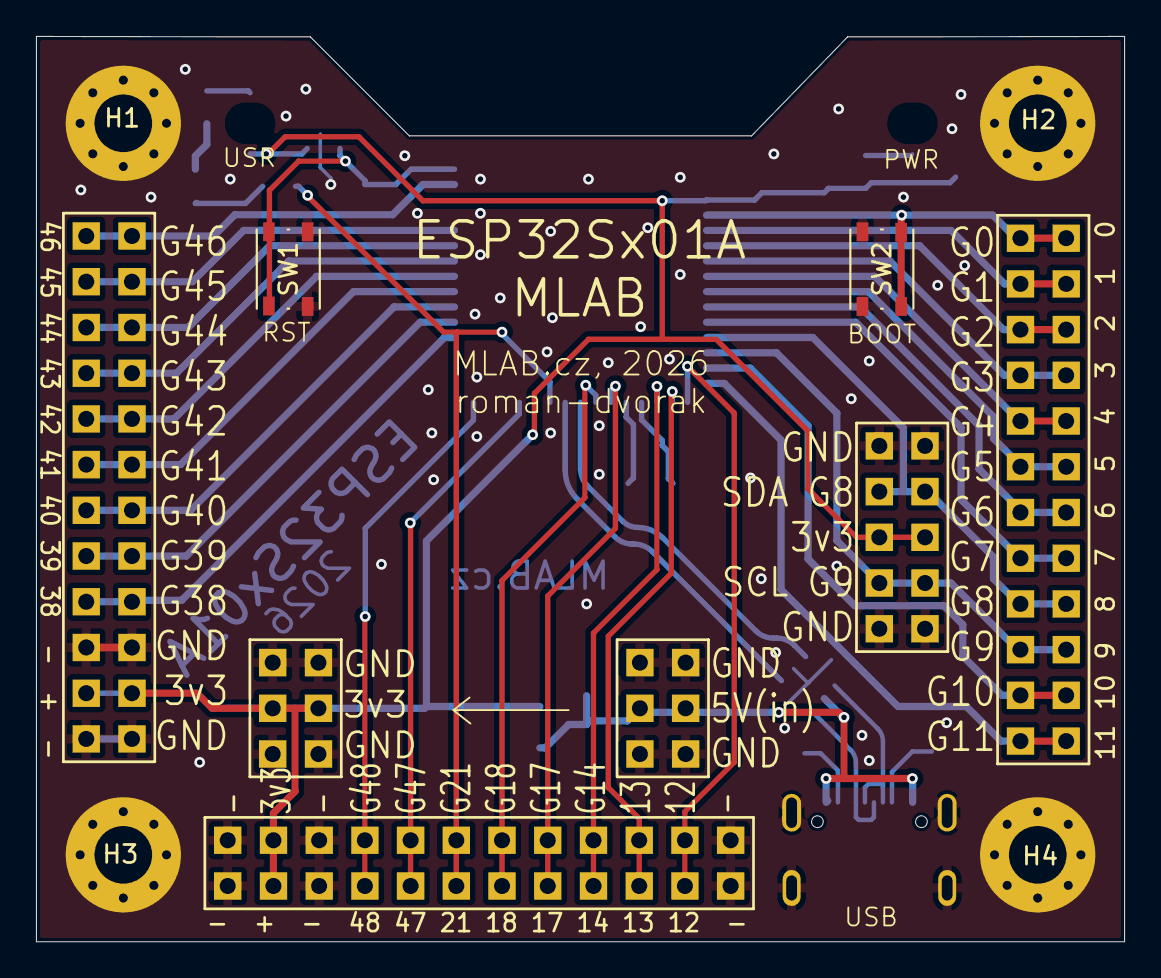
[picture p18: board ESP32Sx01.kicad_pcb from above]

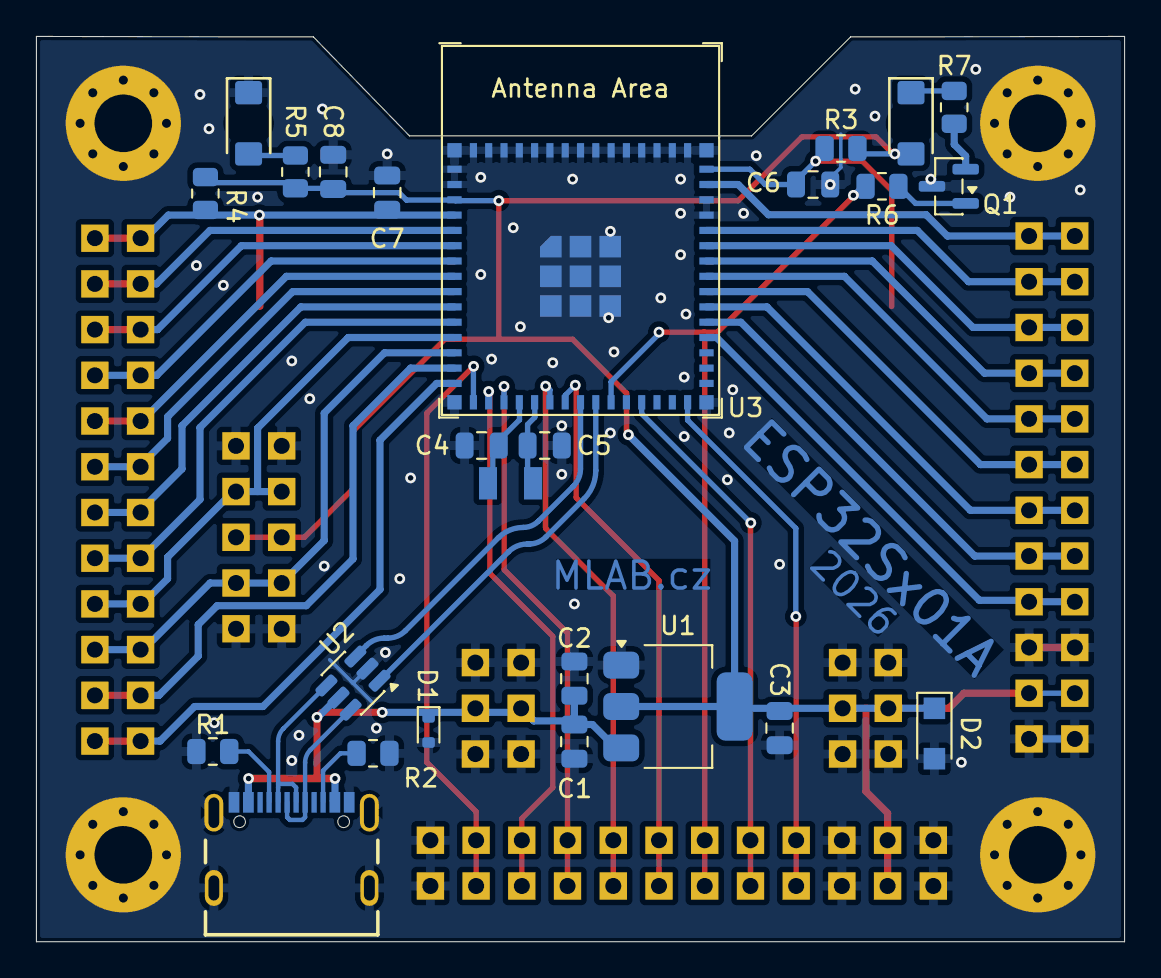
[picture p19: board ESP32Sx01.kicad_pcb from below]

Board: 2 copper layers, 60.5 x 50.3 mm, 37 parts (25 on the bottom side), 45 nets.

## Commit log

2026-01-27 Update title blocks.
    [ESP32Sx01.kicad_pcb, ESP32Sx01.kicad_sch]
2026-01-27 Update actions products
    [ESP32Sx01-B_Adhesive.dxf, ESP32Sx01-B_Courtyard.dxf, ESP32Sx01-B_Cu.dxf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]
2026-02-13 Update of PCB design
    [ESP32Sx01.kicad_pcb, ESP32Sx01.kicad_sch]
2026-02-13 finishing PCB design
    [ESP32Sx01.kicad_pcb, ESP32Sx01.kicad_sch]
2026-02-13 move boot button
    [ESP32Sx01.kicad_pcb, ESP32Sx01.kicad_sch]
2026-02-13 rotate LED to maintain same orientation
    [ESP32Sx01.kicad_pcb]
2026-02-13 minor layout modifications
    [ESP32Sx01.kicad_pcb]
2026-02-14 solve missing anotation in schematics
    [ESP32Sx01.kicad_pcb, ESP32Sx01.kicad_sch]
2026-02-15 add polarity-swap protection
    [ESP32Sx01.kicad_pcb, ESP32Sx01.kicad_sch]
2026-02-15 Automatic update of KiCAD outputs
    [ESP32Sx01.step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]
2026-02-15 Cleanup fab layer. Resolve DRC errors.
    [ESP32Sx01.kicad_pcb, ESP32Sx01.kicad_sch]
2026-02-20 Update UST_IDs.
    [ESP32Sx01.kicad_sch]
2026-02-21 Add UST_ID for Y1.
    [ESP32Sx01.kicad_sch]
